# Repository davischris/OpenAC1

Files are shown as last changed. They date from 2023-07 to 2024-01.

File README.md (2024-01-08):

# OpenAC1

This work is largely based on the work of Tor-Eirik Bakke Lunde (https://github.com/tebl/RC6502-Apple-1-Replica).  I really liked his project and I had just read "Apple 1 Replica Creation: Back to the Garage" by Tom Owad, so I was very interested in making a "workalike" Apple 1.

I wanted to extend this project to include USB keyboard and VGA monitor support, as well as the ability to read programs from an SD card.

This project also includes code from other open source projects including Geoff Graham's VT100 Teminal Emulator (https://geoffg.net/terminal.html) including David Hansel's modification to use a USB keyboard.

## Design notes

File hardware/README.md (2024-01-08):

Schematic and circuit board were designed in KiCAD 6.0

ROM image should be burned to an AT28C64 EEPROM

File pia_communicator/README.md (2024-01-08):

Open .ino file in Arduino IDE for Arduino Nano

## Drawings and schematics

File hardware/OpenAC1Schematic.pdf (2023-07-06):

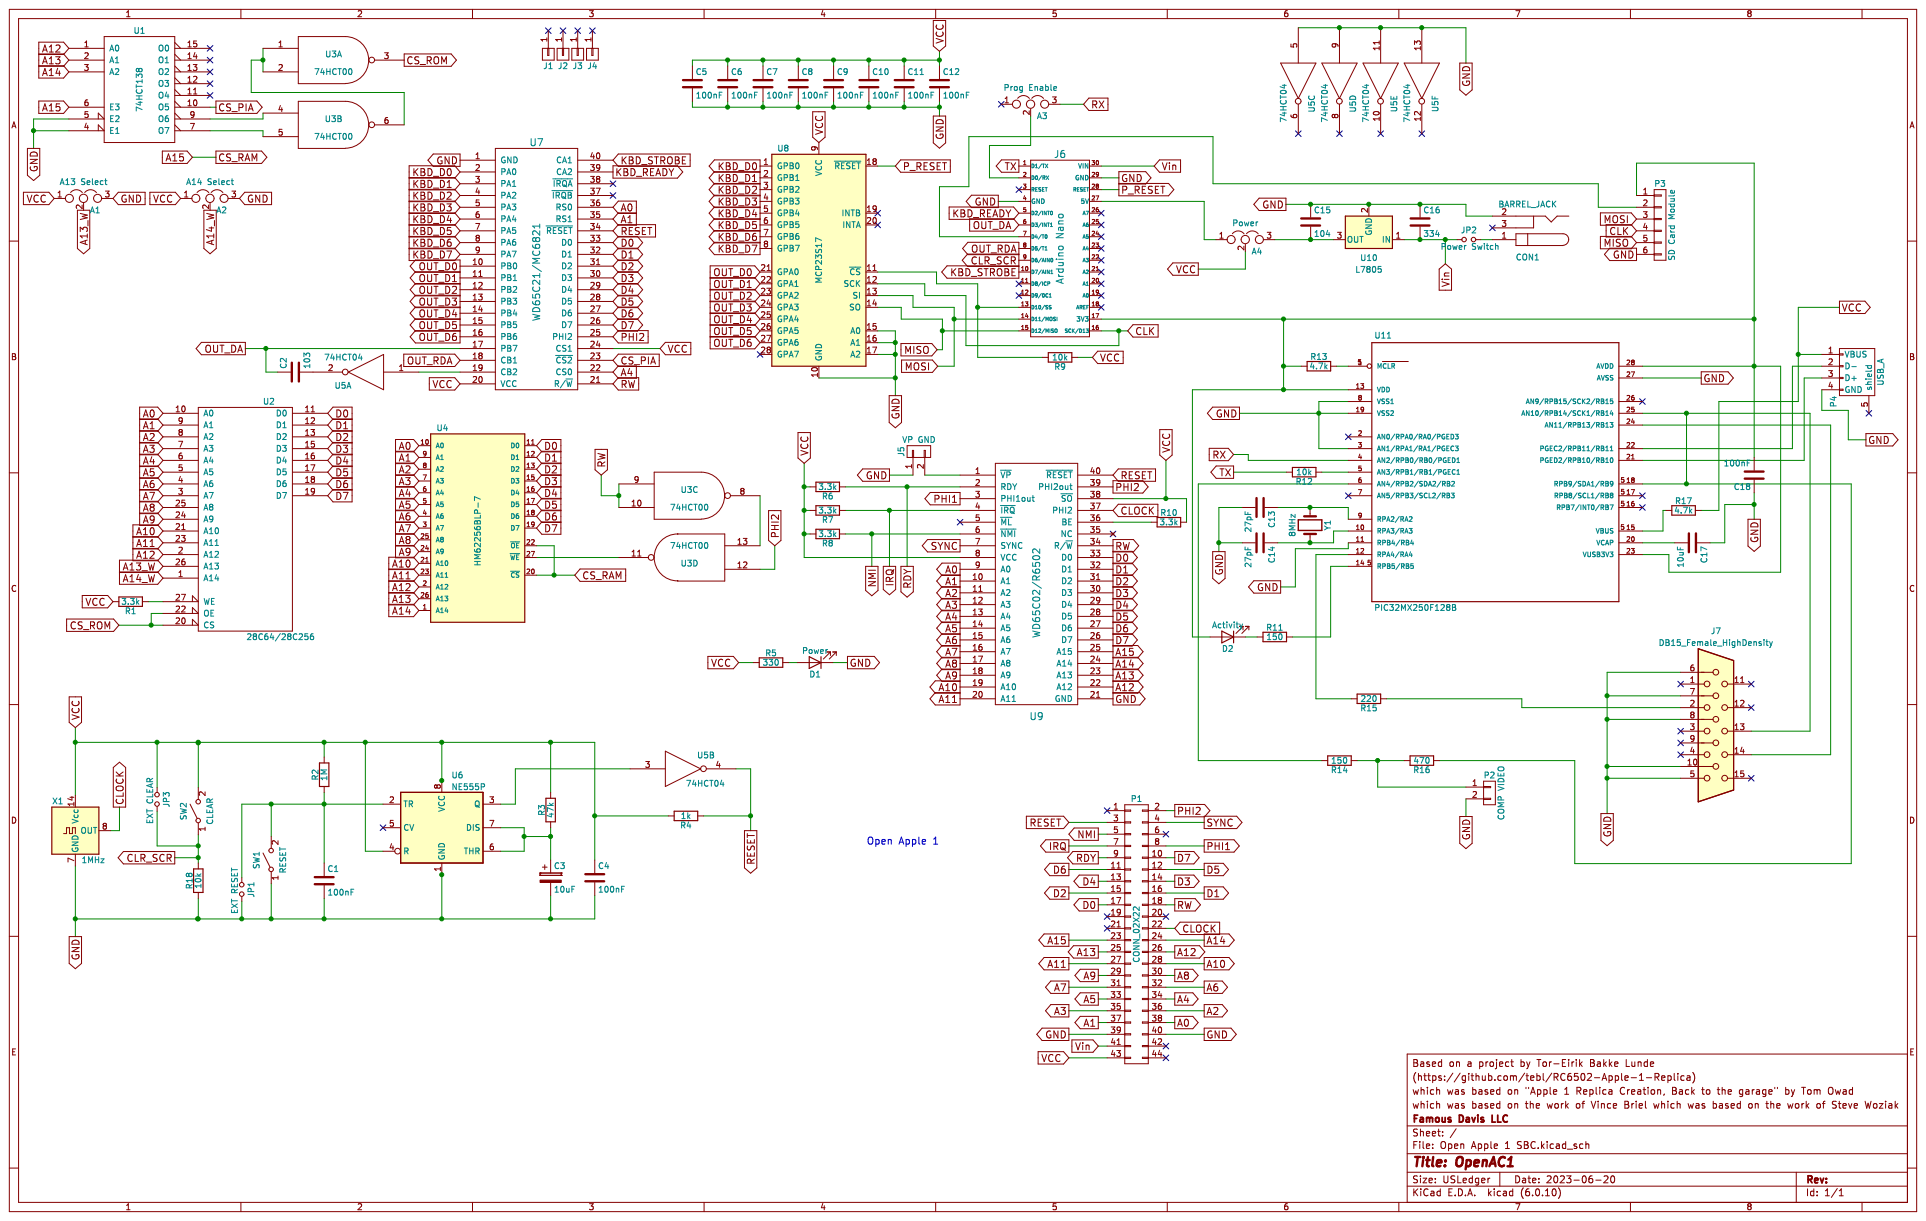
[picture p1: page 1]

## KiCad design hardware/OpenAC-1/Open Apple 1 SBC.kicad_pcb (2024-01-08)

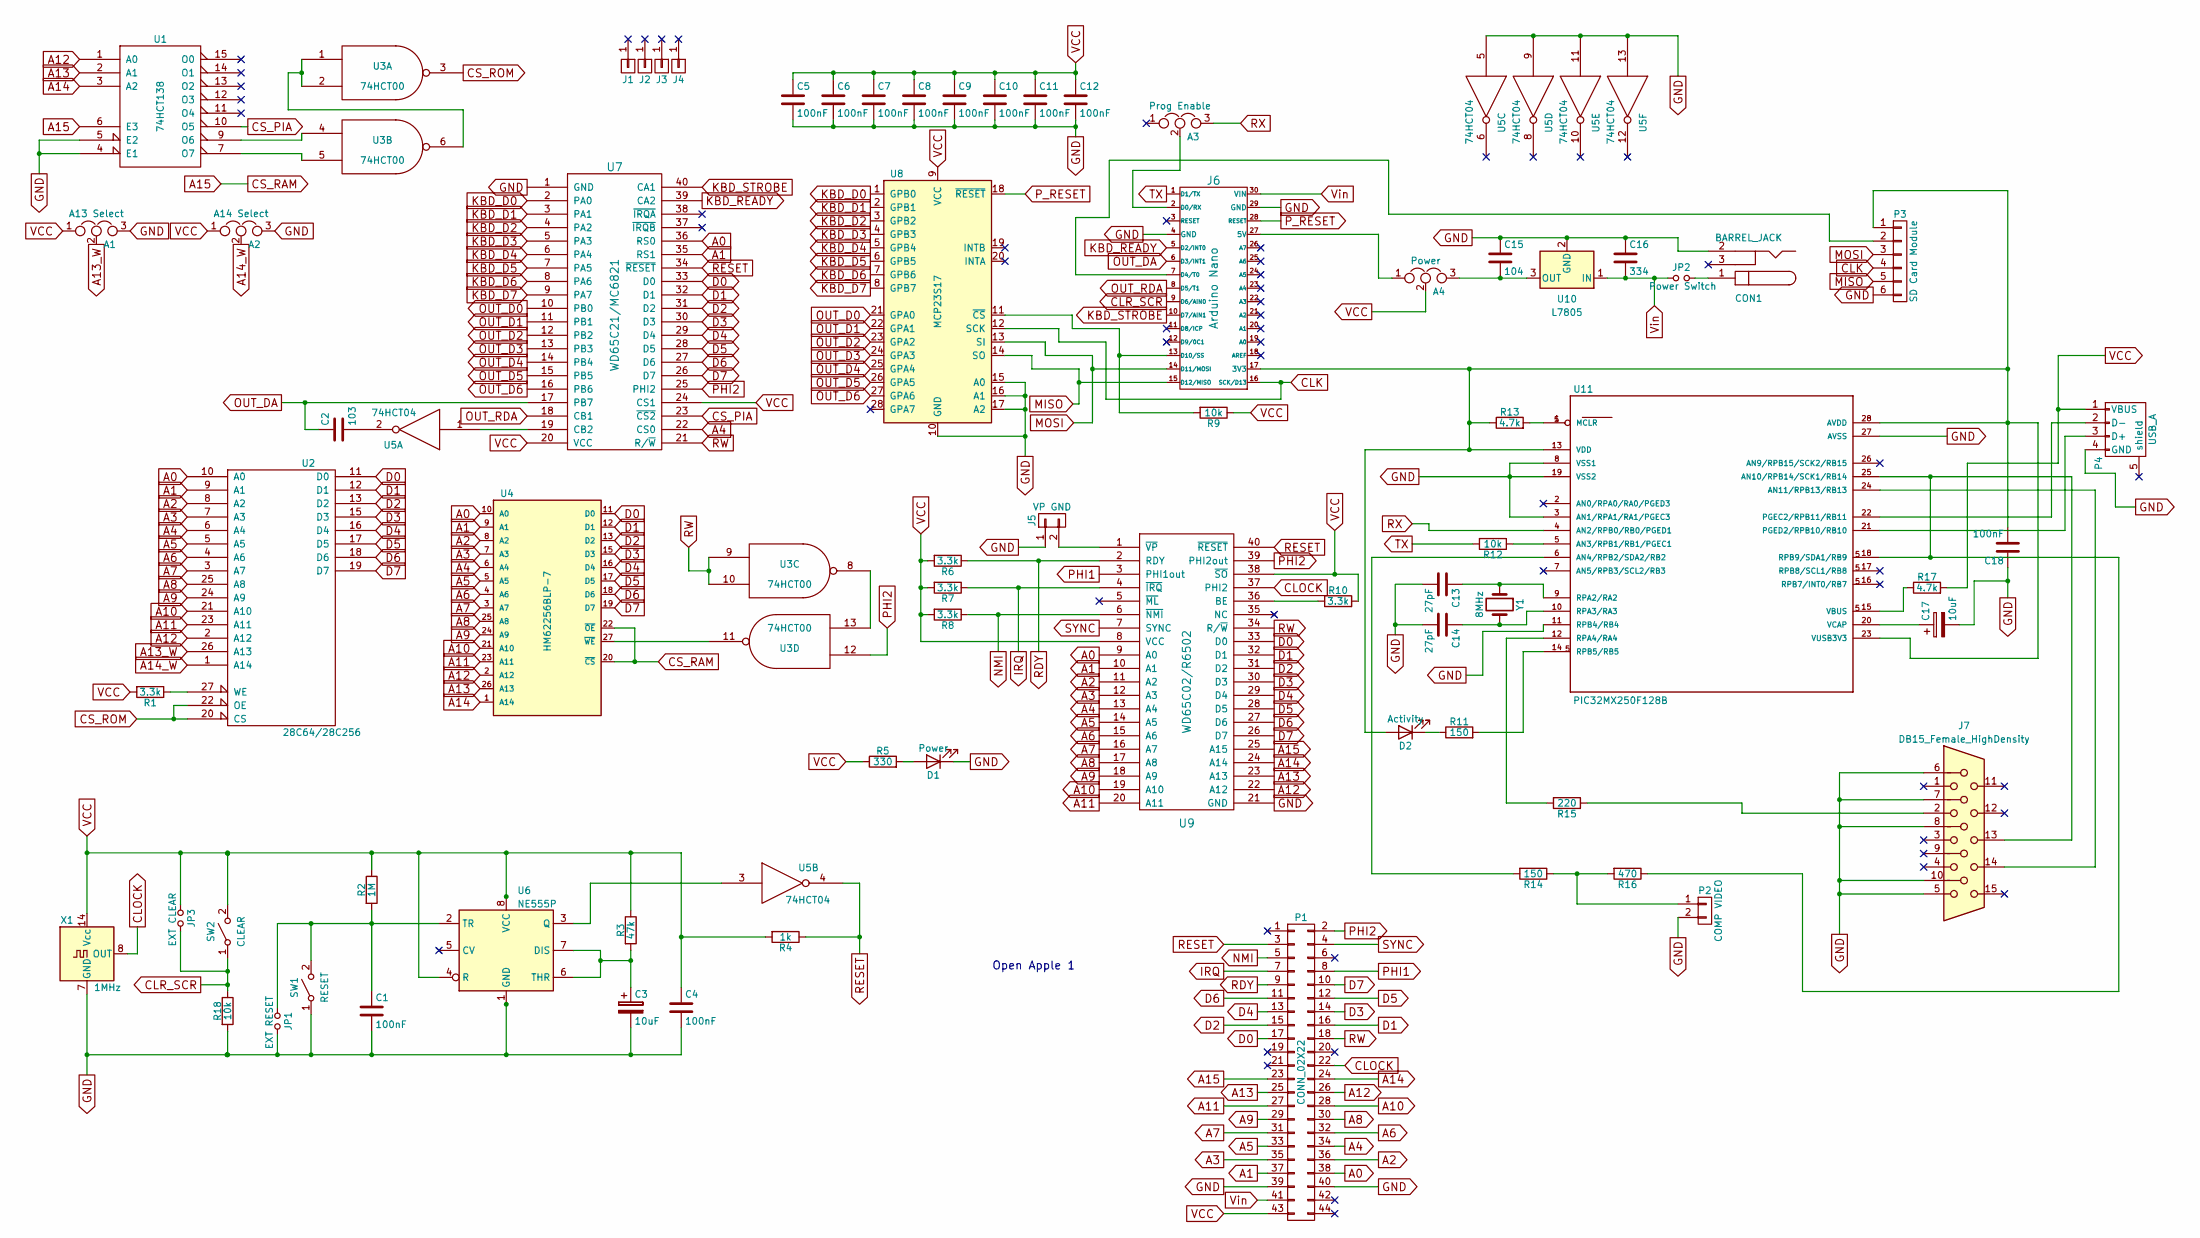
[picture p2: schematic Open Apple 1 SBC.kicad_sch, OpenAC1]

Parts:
A1: A13 Select; PinHeader_1x03_P2.54mm_Vertical
A2: A14 Select; PinHeader_1x03_P2.54mm_Vertical
A3: Prog Enable; PinHeader_1x03_P2.54mm_Vertical
A4: Power; PinHeader_1x03_P2.54mm_Vertical
C1, C4, C5, C6, C7, C8, C9, C10, C11, C12, C18: 100nF; C_Disc_D3.8mm_W2.6mm_P2.50mm
C2: 103; C_Disc_D4.3mm_W1.9mm_P5.00mm
C3, C17: 10uF; CP_Radial_D4.0mm_P2.00mm
C13, C14: 27pF; C_Disc_D3.8mm_W2.6mm_P2.50mm
C15: 104; C_Disc_D4.3mm_W1.9mm_P5.00mm
C16: 334; C_Disc_D4.3mm_W1.9mm_P5.00mm
CON1: BARREL_JACK; BarrelJack_Horizontal
D1: Power; LED_D5.0mm
D2: Activity; LED_D5.0mm
J1, J2, J3, J4: Hole; Mounting
J5: VP GND; PinHeader_1x02_P2.54mm_Vertical
J6: Arduino Nano; Arduino_Nano
J7: DB15_Female_HighDensity; DSUB-15-HD_Female_Horizontal_P2.29x1.98mm_EdgePinOffset3.03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
JP1: EXT RESET; PinHeader_1x02_P2.54mm_Vertical
JP2: Power Switch; PinHeader_1x02_P2.54mm_Vertical
JP3: EXT CLEAR; PinHeader_1x02_P2.54mm_Vertical
P1: CONN_02X22; PinHeader_2x22_P2.54mm_Vertical
P2: COMP VIDEO; PinHeader_1x02_P2.54mm_Vertical
P3: SD Card Module; PinHeader_1x06_P2.54mm_Vertical
P4: USB_A
R1, R6, R7, R8, R10: 3.3k; R_Axial_DIN0207_L6.3mm_D2.5mm_P10.16mm_Horizontal
R2: 1M; R_Axial_DIN0207_L6.3mm_D2.5mm_P10.16mm_Horizontal
R3: 47k; R_Axial_DIN0207_L6.3mm_D2.5mm_P10.16mm_Horizontal
R4: 1k; R_Axial_DIN0207_L6.3mm_D2.5mm_P10.16mm_Horizontal
R5: 330; R_Axial_DIN0207_L6.3mm_D2.5mm_P10.16mm_Horizontal
R9, R12, R18: 10k; R_Axial_DIN0207_L6.3mm_D2.5mm_P10.16mm_Horizontal
R11, R14: 150; R_Axial_DIN0207_L6.3mm_D2.5mm_P10.16mm_Horizontal
R13, R17: 4.7k; R_Axial_DIN0207_L6.3mm_D2.5mm_P10.16mm_Horizontal
R15: 220; R_Axial_DIN0207_L6.3mm_D2.5mm_P10.16mm_Horizontal
R16: 470; R_Axial_DIN0207_L6.3mm_D2.5mm_P10.16mm_Horizontal
SW1: RESET; SW_PUSH_6mm
SW2: CLEAR; SW_PUSH_6mm
U1: 74HCT138; DIP-16_W7.62mm
U2: 28C64/28C256; DIP-28_W15.24mm
U3: 74HCT00; DIP-14_W7.62mm
U4: HM62256BLP-7; DIP-28_W15.24mm
U5: 74HCT04; DIP-14_W7.62mm
U6: NE555P; DIP-8_W7.62mm
U7: WD65C21/MC6821; DIP-40_W15.24mm
U8: MCP23S17; DIP-28_W7.62mm
U9: WD65C02/R6502; DIP-40_W15.24mm
U10: L7805; TO-220-3_Vertical
U11: PIC32MX250F128B; DIP-28_W7.62mm
X1: 1MHz; Oscillator_DIP-14
Y1: 8MHz; Crystal_HC49-U_Vertical

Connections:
A0: P1.38, U2.10 (A0), U4.10 (A0), U7.36 (RS0), U9.9 (A0)
A1: P1.37, U2.9 (A1), U4.9 (A1), U7.35 (RS1), U9.10 (A1)
A2: P1.36, U2.8 (A2), U4.8 (A2), U9.11 (A2)
A3: P1.35, U2.7 (A3), U4.7 (A3), U9.12 (A3)
A4: P1.34, U2.6 (A4), U4.6 (A4), U7.22 (CS0), U9.13 (A4)
A5: P1.33, U2.5 (A5), U4.5 (A5), U9.14 (A5)
A6: P1.32, U2.4 (A6), U4.4 (A6), U9.15 (A6)
A7: P1.31, U2.3 (A7), U4.3 (A7), U9.16 (A7)
A8: P1.30, U2.25 (A8), U4.25 (A8), U9.17 (A8)
A9: P1.29, U2.24 (A9), U4.24 (A9), U9.18 (A9)
A10: P1.28, U2.21 (A10), U4.21 (A10), U9.19 (A10)
A11: P1.27, U2.23 (A11), U4.23 (A11), U9.20 (A11)
A12: P1.26, U1.1 (A0), U2.2 (A12), U4.2 (A12), U9.22 (A12)
A13: P1.25, U1.2 (A1), U4.26 (A13), U9.23 (A13)
A13_W: A1.2, U2.26 (A13)
A14: P1.24, U1.3 (A2), U4.1 (A14), U9.24 (A14)
A14_W: A2.2, U2.1 (A14)
A15: P1.23, U1.6 (E3), U4.20 (~CS), U4.22 (~OE), U9.25 (A15)
CLK: J6.16 (SCK/D13), P3.4, U8.12 (SCK)
CLOCK: P1.22, U9.37 (PHI2), X1.8 (OUT)
CLR_SCR: J6.9 (D6/AIN0), JP3.2, R18.1, SW2.1 (A)
CS_PIA: U1.10 (O5), U7.23 (~CS2)
CS_ROM: U2.20 (CS), U2.22 (OE), U3.3
D0: P1.17, U2.11 (D0), U4.11 (D0), U7.33 (D0), U9.33 (D0)
D1: P1.16, U2.12 (D1), U4.12 (D1), U7.32 (D1), U9.32 (D1)
D2: P1.15, U2.13 (D2), U4.13 (D2), U7.31 (D2), U9.31 (D2)
D3: P1.14, U2.15 (D3), U4.15 (D3), U7.30 (D3), U9.30 (D3)
D4: P1.13, U2.16 (D4), U4.16 (D4), U7.29 (D4), U9.29 (D4)
D5: P1.12, U2.17 (D5), U4.17 (D5), U7.28 (D5), U9.28 (D5)
D6: P1.11, U2.18 (D6), U4.18 (D6), U7.27 (D6), U9.27 (D6)
D7: P1.10, U2.19 (D7), U4.19 (D7), U7.26 (D7), U9.26 (D7)
GND: A1.3, A2.3, C1.2, C3.2, C4.2, C5.2, C6.2, C7.2, C8.2, C9.2, C10.2, C11.2, C12.2, C13.2, C14.2, C15.1, C16.1, C17.2, C18.1, CON1.2, D1.1 (K), J5.1, J6.4 (GND), J6.29 (GND), J7.5, J7.6, J7.7, J7.8, J7.10, JP1.2, P1.39, P1.40, P2.2, P3.6, P4.4 (GND), R18.2, SW1.1 (A), U1.4 (E1), U1.5 (E2), U1.8 (GND), U2.14 (GND), U3.7 (GND), U4.14 (GND), U5.5, U5.7 (GND), U5.9, U5.11, U5.13, U6.1 (GND), U7.1 (GND), U8.10 (GND), U8.15 (A0), U8.16 (A1), U8.17 (A2), U9.21 (GND), U10.2 (GND), U11.3 (AN1/RPA1/RA1/PGEC3), U11.8 (VSS1), U11.11 (RPB4/RB4), U11.19 (VSS2), U11.27 (AVSS), X1.7 (GND)
IRQ: P1.7, R7.1, U9.4 (~IRQ)
KBD_D0: U7.2 (PA0), U8.1 (GPB0)
KBD_D1: U7.3 (PA1), U8.2 (GPB1)
KBD_D2: U7.4 (PA2), U8.3 (GPB2)
KBD_D3: U7.5 (PA3), U8.4 (GPB3)
KBD_D4: U7.6 (PA4), U8.5 (GPB4)
KBD_D5: U7.7 (PA5), U8.6 (GPB5)
KBD_D6: U7.8 (PA6), U8.7 (GPB6)
KBD_D7: U7.9 (PA7), U8.8 (GPB7)
KBD_READY: J6.5 (D2/INT0), U7.39 (CA2)
KBD_STROBE: J6.10 (D7/AIN1), U7.40 (CA1)
MISO: J6.15 (D12/MISO), P3.5, U8.14 (SO)
MOSI: J6.14 (D11/MOSI), P3.3, U8.13 (SI)
NMI: P1.5, R8.1, U9.6 (~NMI)
unnamed: A3.2, J6.2 (D0/RX)
unnamed: A4.1, J6.27 (5V)
unnamed: A4.3, C15.2, U10.3 (OUT)
unnamed: C1.1, JP1.1, R2.2, SW1.2 (B), U6.2 (TR)
unnamed: C2.2, U5.2
unnamed: C3.1, R3.2, U6.6 (THR), U6.7 (DIS)
unnamed: C13.1, U11.9 (RPA2/RA2), Y1.1
unnamed: C14.1, U11.10 (RPA3/RA3), Y1.2
unnamed: C17.1, U11.20 (VCAP)
unnamed: C18.2, D2.2 (A), J6.17 (3V3), P3.1, R13.1, U11.13 (VDD), U11.23 (VUSB3V3), U11.28 (AVDD)
unnamed: CON1.1, JP2.2
unnamed: D1.2 (A), R5.2
unnamed: D2.1 (K), R11.1
unnamed: J5.2, U9.1 (~VP)
unnamed: J6.7 (D4/T0), P3.2
unnamed: J6.13 (D10/SS), R9.2, U8.11 (~CS)
unnamed: J7.2, R15.1
unnamed: J7.13, R16.1, U11.18 (RPB9/SDA1/RB9), U11.25 (AN10/RPB14/SCK1/RB14)
unnamed: J7.14, U11.24 (AN11/RPB13/RB13)
unnamed: P2.1, R14.1, R16.2
unnamed: P4.2 (D-), U11.22 (PGEC2/RPB11/RB11)
unnamed: P4.3 (D+), U11.21 (PGED2/RPB10/RB10)
unnamed: R1.1, U2.27 (WE)
unnamed: R10.1, U9.36 (BE)
unnamed: R11.2, U11.14 (RPB5/RB5)
unnamed: R12.1, U11.5 (AN3/RPB1/RB1/PGEC1)
unnamed: R13.2, U11.1 (MCLR)
unnamed: R14.2, U11.6 (AN4/RPB2/SDA2/RB2)
unnamed: R15.2, U11.12 (RPA4/RA4)
unnamed: R17.1, U11.15 (VBUS)
unnamed: U1.7 (O7), U3.5
unnamed: U1.9 (O6), U3.4
unnamed: U3.1, U3.2, U3.6
unnamed: U3.11, U4.27 (~WE)
unnamed: U3.8, U3.13
unnamed: U5.1, U7.19 (CB2)
unnamed: U5.3, U6.3 (Q)
OUT_D0: U7.10 (PB0), U8.21 (GPA0)
OUT_D1: U7.11 (PB1), U8.22 (GPA1)
OUT_D2: U7.12 (PB2), U8.23 (GPA2)
OUT_D3: U7.13 (PB3), U8.24 (GPA3)
OUT_D4: U7.14 (PB4), U8.25 (GPA4)
OUT_D5: U7.15 (PB5), U8.26 (GPA5)
OUT_D6: U7.16 (PB6), U8.27 (GPA6)
OUT_DA: C2.1, J6.6 (D3/INT1), U7.17 (PB7)
OUT_RDA: J6.8 (D5/T1), U7.18 (CB1)
PHI1: P1.8, U9.3 (PHI1out)
PHI2: P1.2, U3.12, U7.25 (PHI2), U9.39 (PHI2out)
P_RESET: J6.28 (RESET), U8.18 (~RESET)
RDY: P1.9, R6.1, U9.2 (RDY)
RESET: P1.3, R4.1, U5.4, U7.34 (~RESET), U9.40 (~RESET)
RW: P1.18, U3.9, U3.10, U7.21 (R/~W), U9.34 (R/~W)
RX: A3.3, U11.4 (AN2/RPB0/RB0/PGED1)
SYNC: P1.4, U9.7 (SYNC)
TX: J6.1 (D1/TX), R12.2
VCC: A1.1, A2.1, A4.2, C4.1, C5.1, C6.1, C7.1, C8.1, C9.1, C10.1, C11.1, C12.1, JP3.1, P1.43, P4.1 (VBUS), R1.2, R2.1, R3.1, R4.2, R5.1, R6.2, R7.2, R8.2, R9.1, R10.2, R17.2, SW2.2 (B), U1.16 (VCC), U2.28 (VCC), U3.14 (VCC), U4.28 (VCC), U5.14 (VCC), U6.4 (R), U6.8 (VCC), U7.20 (VCC), U7.24 (CS1), U8.9 (VCC), U9.8 (VCC), U9.38 (~SO), X1.14 (Vcc)
Vin: C16.2, J6.30 (VIN), JP2.1, P1.41, U10.1 (IN)

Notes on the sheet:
Open Apple 1

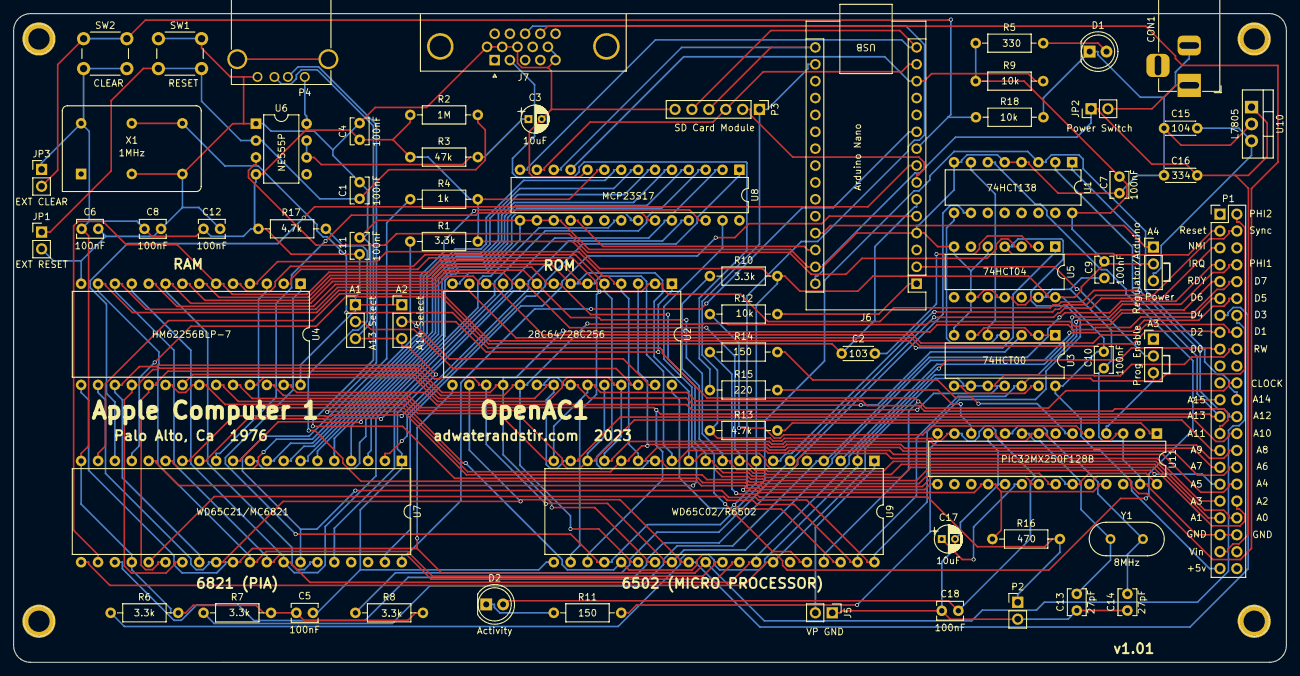
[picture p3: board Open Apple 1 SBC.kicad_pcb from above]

Board: 2 copper layers, 191.5 x 97.6 mm, 72 parts (0 on the bottom side), 103 nets.

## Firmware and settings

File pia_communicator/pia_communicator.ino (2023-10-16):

#include <SPI.h>
#include <MCP23S17.h>
#include <SD.h>

#define KBD_INTERRUPT_ENABLE true
#define KBD_SEND_TIMEOUT_MS 2000

#define IO_SS 10

#define IO_VIDEO 0
#define IO_VIDEO_D0 0
#define IO_VIDEO_D6 6
#define VIDEO_RDA 5
#define VIDEO_DA 3

#define IO_KBD 1
#define IO_KBD_D0 8
#define IO_KBD_D6 14
#define IO_KBD_DA 15
#define KBD_READY 2
#define KBD_STROBE 7    //was 4, needed to free up for sd module
#define LED 13
#define CLRSCR 6

// How long to delay after sending a character to video terminal (ms)
#define VIDEO_CHARACTER_DELAY 5
// How long to delay after sending a character to the PIA/6802
#define PIA_CHARACTER_DELAY 5
// How long to delay after writing a full line to the PIA/6802
#define PIA_LINE_DELAY 150

static int delay_after_line_ms = PIA_LINE_DELAY;
static volatile char video_byte;
static bool loading_file;

MCP23S17 bridge(&SPI, IO_SS, 0);
File root;
const int chipSelect = 4;
String command;
File firstFile;
File myRecFile;
int captureType;
bool firstByte;
int countUp = -32767;
int buttonState = 0;        // current state of the button

static volatile bool video_data_ready;
static volatile bool keyboard_data_sent_ok;

static void on_video_data_ready(void) {
  digitalWrite(VIDEO_RDA, LOW);
  video_byte = bridge.readPort(IO_VIDEO) & 127;
  video_data_ready = true;
}

static void on_keyboard_data_ack(void) {
  keyboard_data_sent_ok = true;
}

/**
 * We signal to the 6802/PIA that we are ready to accept
 * video data by a low-to-high transition on the VIDEO_RDA pin.
 */
static void signal_ready_for_video(void) {
  digitalWrite(VIDEO_RDA, LOW);
  delay(100);
  digitalWrite(VIDEO_RDA, HIGH);
}

void setup() {
  pinMode(LED, OUTPUT);
  Serial.begin(38400);
  configure_pins();
  configure_bridge();
  //output_status();
  Serial.println("\033[f");
  Serial.print(".");

  Serial.print(".");
  digitalWrite(VIDEO_RDA, LOW);
  delay(2000);
  digitalWrite(VIDEO_RDA, HIGH);
  Serial.println("\033[2J");
  delay(100);
  Serial.println("\033[f");
  loading_file = false;
}

void configure_pins() {
  pinMode(KBD_READY, INPUT);
  pinMode(VIDEO_DA, INPUT);
  pinMode(KBD_STROBE, OUTPUT);
  pinMode(VIDEO_RDA, OUTPUT);

  // initialize the button pin as a input:
  pinMode(CLRSCR, INPUT);

  /* Test the use of interrupts for communication with the PIA */
  attachInterrupt(digitalPinToInterrupt(KBD_READY), on_keyboard_data_ack, FALLING);
  attachInterrupt(digitalPinToInterrupt(VIDEO_DA), on_video_data_ready, RISING);
}

void configure_bridge() {
  bridge.begin();

  /* Configure video section 
  for (int i = IO_VIDEO_D0; i <= IO_VIDEO_D6; i++) {
    bridge.pinMode(i, INPUT);
  }*/
  bridge.pinMode(7, INPUT_PULLUP);

  /* Configure keyboard section */
  for (int i = 8; i <= 15; i++) {
    bridge.pinMode(i, OUTPUT);
  }
}

void show_directory() {
  int numTabs = 0;
  Serial.println(" ");
  root = SD.open("/");
  printDirectory(root, 0);
  root.close();
}

String formatFilename(File entry) {
  char s[80];
  char n[70];
  String tmp;
  int fileLen;
  
  tmp = entry.name();
  tmp.toUpperCase();
  tmp.toCharArray(n, tmp.length()+1);
  fileLen = entry.size()/1000;
  if (fileLen == 0)
    fileLen = 1;
  if (tmp.endsWith("BIN")) {
    sprintf(s, "B  %03d  %s", fileLen, n);
  } else if (tmp.endsWith("BAS")) {
    sprintf(s, "I  %03d  %s", fileLen, n);
  }

  //remove files that begin with "." (in case this card was inserted into a Mac)
  if (n[0] == '.' || n[0] == '_')
    s[0] = '\0';
  return String(s);
}

void printDirectory(File dir, int numTabs) {
  int numFiles = 0;
  String fName;
  
  while (true) {

    File entry =  dir.openNextFile();
    if (! entry) {
      // no more files
      dir.rewindDirectory();
      break;
    }
    for (uint8_t i = 0; i < numTabs; i++) {
      Serial.print('\t');
    }
    if (!entry.isDirectory()) {
      if (numFiles == 0) {  //we have to do this goofy thing because the catalog will skip the first file after loading a program
        if (firstFile.name() == "")
          firstFile = entry;
        else
          if (firstFile.name() != entry.name()) {
            fName = formatFilename(firstFile);
            if (fName.charAt(0) == 'B' || fName.charAt(0) == 'I')
            {
              Serial.println(fName);
              numFiles++;
            }
          }
      }
      fName = formatFilename(entry);
      if (fName.charAt(0) == 'B' || fName.charAt(0) == 'I')
      {
        Serial.println(fName);
        numFiles++;
      }
    }
    entry.close();

    //pause for long listings
    if (numFiles > 0 && numFiles % 18 == 0) {
      Serial.println("Press any key...");
      Serial.flush();
      while(!Serial.available()) {
      }
      int c = Serial.read();
      Serial.flush();
    }
  }
}

void print_hex(byte value) {
  print_hex(value, true);
}

void print_hex(byte value, bool newline) {
  if (value <= 0xF) {
    Serial.print("0x0");
  } else {
    Serial.print("0x");
  }

  if (newline) Serial.println(value, HEX);
  else Serial.print(value, HEX);
}

void serial_receive() {
  if (Serial.available() > 0) {
    int c = Serial.read();
    pia_send(c);
  }
}

void load_file(String filename, int start_line = -1, int end_line = -1) {
  if (!SD.exists(filename)) {
    Serial.println("File does not exist.");
    return;
  }
  loading_file = true;
  
  File myFile = SD.open(filename);

  //switch to BASIC or Wozmon based on the file extension
  int len = strlen(myFile.name());
  if (strstr(strlwr(myFile.name() + (len - 4)), ".bas"))
  {
    for(auto x : "E000R")
    {
      send_key(x);
      process_video();
    }
    send_key(13);
    process_video();
    delay(500);    
  } else if (strstr(strlwr(myFile.name() + (len - 4)), ".bin"))
  {
    for(auto x : "CALL -151")
    {
      send_key(x);
      process_video();
    }
    send_key(13);
    process_video();
    delay(500);    
  }

  if (start_line != -1) {
    if (end_line == -1) {
      // Assume user only wants to load a single line
      end_line = start_line;
    }
    else if (end_line <= start_line) {
      end_line = start_line + 10;
    }
    Serial.print("Loading lines ");
    Serial.print(String(start_line));
    Serial.print(" to ");
    Serial.println(String(end_line));
  }

  if (!myFile) {
    Serial.println("Could not open file ...");
    loading_file = false;
    return;
  }

  int line_number = 1;
  char last;
  while (myFile.available()) {
    char ch = myFile.read();
    if (last == 10 || last == 13 && (ch != 10 && ch != 13)) {
      line_number++;
    }
    if (ch == 10) ch = 13;

    if (start_line == -1) {
      // We are transmitting all lines ...
      send_key(ch);
      process_video();
    }
    else if (line_number >= start_line && line_number <= end_line) {
      // We are transmitting only selected lines ...
      send_key(ch);
      process_video();
    }
    last = ch;
  }
  myFile.rewindDirectory();
  myFile.close();
  loading_file = false;
  if (firstFile.name() != "")              //we have to do this because some goofy thing makes the catalog listing stuck on whatever file was loaded
    bool b = SD.exists(firstFile.name());
}

String getValue(String data, char separator, int index)
{
  int found = 0;
  int strIndex[] = {0, -1};
  int maxIndex = data.length()-1;

  for(int i=0; i<=maxIndex && found<=index; i++){
    if(data.charAt(i)==separator || i==maxIndex){
        found++;
        strIndex[0] = strIndex[1]+1;
        strIndex[1] = (i == maxIndex) ? i+1 : i;
    }
  }

  return found>index ? data.substring(strIndex[0], strIndex[1]) : "";
}

void pia_send(int c) {
  char ch;

  c = map_to_ascii(c);

  /* Output the actual keys as long as it's supported */
  if (c < 96) {
    if (c == 13) { 
      int cmdLen = command.length();
      //Serial.println("\rCommand: " + command);
      if (cmdLen > 6) {   //if it's short, we don't need to parse it.
        command.trim();
        if (command == "CATALOG") {
          if (!SD.begin(chipSelect))
            Serial.println("initialize SD card failed");
          else
            show_directory();
          //send_key(27);
          for (int i = 0; i < cmdLen; i++) {
            send_key(95);
          }
          c = 13;
        } else if (command.startsWith("LOAD ", 0)) {
          Serial.println("");
          for (int i = 0; i < cmdLen; i++) {
            send_key(95);
          }
          send_key(13);
          if (!SD.begin(chipSelect))
            Serial.println("initialize SD card failed");
          else
          {
            String filename = command.substring(5);
            int start_line = -1, end_line = -1;
            if (filename) {
              int pos = filename.indexOf(' ');
              if (pos != -1) {
                String s = filename.substring(pos + 1); // start
                filename = filename.substring(0, pos);
                int pos2 = s.indexOf(',');
                if (pos2 != -1) {
                  String e = s.substring(pos2 + 1); // end
                  s = s.substring(0, pos2);
                  end_line = e.toInt();
                }
                start_line = s.toInt();
              }
              if (start_line == 0) {
                start_line = -1;
              }
              load_file(filename, start_line, end_line);
            }
            else {
              Serial.println("You must specify a filename.");
            }
          }
        } else if (command.startsWith("TIMEOUT", 0)) {
          if (command.length() == 7) {
            Serial.println("\n\rLINE TIMEOUT VALUE IS " + String(delay_after_line_ms));
          }
          else {
            String timeout = command.substring(8);
            delay_after_line_ms = timeout.toInt();
            Serial.println("\n\rLINE TIMEOUT VALUE CHANGED TO " + String(delay_after_line_ms));
          }
          for (int i = 0; i < cmdLen; i++) {
            send_key(95);
          }
          c = 13;
        }
      }
      command = "";
    } else {
      char ch = c;
      //if this is a rubout character, then delete the last character from our command string
      if (ch == '_') {
        int lastIndex = command.length() - 1;
        if (lastIndex >= 0)
          command.remove(lastIndex);
      } else
        command.concat(ch);
    }

    send_key(c);
  }
}

/*
   Transmit character

   @note    This function will return 1 if an acknowledgement is not received
            within the specified time.

   @return  0 on success
            1 on failure
*/
int resend_key(int c) {
  /* Make sure STROBE signal is off */
  digitalWrite(KBD_STROBE, LOW);

  delayMicroseconds(750);
  /* Notify PIA that we have sent a new keyboard character */
  digitalWrite(KBD_STROBE, HIGH);
  
  //we're skipping the rest of this process for now.  It seems to cause more troubles than it solves.
  if (!loading_file) {
    signal_ready_for_video();
    return 0;
  }

  /* Wait for PIA to acknowledge this.
    -> We are waiting for a falling edge on the KBD_READY pin.
    -> Once this occurs the keyboard_data_sent_ok flag will be set in the interrupt
  */
  uint32_t t_send = millis();
  while (!keyboard_data_sent_ok) {
    // Ensure we process any new video data while waiting ...
    //process_video();  // Remove this line because it was causing repeating characters on the video display
    uint32_t t_now = millis();
    if (t_now - t_send >= KBD_SEND_TIMEOUT_MS) {
      Serial.println("KBD TIMEOUT");
      return 1;
    }
  }

  return 0;
}

void delay_while_processing_video(int ms) {
  uint32_t t_start = millis();
  while (1) {
    process_video();
    uint32_t t_now = millis();
    if (t_now >= t_start + ms) {
      break;
    }
  }
}

void send_key(int c) {
  const int max_tries = 3;

  /* Write new character on I/O expander */
  bridge.writePort(IO_KBD, c | 128);

  /*
    Notify 6802 and/or PIA that a new character is waiting to be read, and
    then wait for an acknowledgement.
  */
  int attempt = 1;
  int rc = 1;
  while (rc != 0) {
    rc = resend_key(c);
    if (rc == 0) {
      break; // succeeded
    }
    // If we did not receive an acknowledgement that the character
    // was read, try again. Maybe the PIA or 6802 just missed the
    // relevant transition.
    if (attempt++ >= max_tries) {
      Serial.println("TOO MANY ATTEMPTS. SKIPPING CHARACTER.");
      break;
    }
    /** 
     * The 6802 might be stuck in a loop waiting to send us video 
     * data - as it might have missed our last 'ready for video'
     * signal.
     * Just re-signal that we are ready.
     */
    signal_ready_for_video();
  }

  keyboard_data_sent_ok = false;
  digitalWrite(KBD_STROBE, LOW);
  if (c == 13) {
    // Use a longer delay after sending a full line - in case
    // the 6802 needs more time to process
    delay_while_processing_video(delay_after_line_ms);
  }
  else {
    delay(PIA_CHARACTER_DELAY);
  }
}

char map_to_ascii(int c) {
  if (c >= 128) {
    Serial.print("Non-printable character: 0x");
    Serial.println(c, HEX);
  }
  /* Convert ESC key */
  if (c == 203) {
    c = 27;
  }

  /* Ctrl A-Z */
  if (c > 576 && c < 603) {
    c -= 576;
  }

  /* Convert lowercase keys to UPPERCASE */
  if (c > 96 && c < 123) {
    c -= 32;
  }

  /* Convert backspace to underscore */
  if (c == 8) {
    c = 95;
  }

  return c;
}

char send_ascii(char c) {
  switch (c) {
    case 0x0d: Serial.println(); /* Replace CR with LF */
    default:
      Serial.print(c);
  }
}

void process_video(void) {
  if (video_data_ready) {
    video_data_ready = false;
    send_ascii(video_byte);
    
    delay(VIDEO_CHARACTER_DELAY);
    digitalWrite(VIDEO_RDA, HIGH);
  } 
  else if (!loading_file) {
    countUp++;
    if (countUp == 32767) {
      signal_ready_for_video();
      countUp = -32767;
    }
  }
}

void loop() {
  // read the pushbutton input pin:
  buttonState = digitalRead(CLRSCR);
  if (buttonState == HIGH) {
    Serial.println("\033[2J");
    delay(100);
    Serial.println("\033[f");
  }
  serial_receive();
  // serial_transmit();
  process_video();
}

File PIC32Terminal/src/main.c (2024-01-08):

/*****************************************************************************************************************************

Main.c

	Copyright (C) 2014 Geoff Graham (projects@geoffg.net)
	All rights reserved.

	This file and the program created from it are FREE FOR COMMERCIAL AND
	NON-COMMERCIAL USE as long as the following conditions are aheared to.

	Copyright remains Geoff Graham's, and as such any Copyright notices in the
	code are not to be removed.  If this code is used in a product, Geoff Graham
	should be given attribution as the author of the parts used.  This can be in
	the form of a textual message at program startup or in documentation (online
	or textual) provided with the program or product.

	Redistribution and use in source and binary forms, with or without modification,
	are permitted provided that the following conditions  are met:
	1. Redistributions of source code must retain the copyright notice, this list
	   of conditions and the following disclaimer.
	2. Redistributions in binary form must reproduce the above copyright notice, this
	   list of conditions and the following disclaimer in the documentation and/or
	   other materials provided with the distribution.
	3. All advertising materials mentioning features or use of this software must
	   display the following acknowledgement:
	   This product includes software developed by Geoff Graham (projects@geoffg.net)

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
	The licence and distribution terms for any publically available version or
	derivative of this code cannot be changed.  i.e. this code cannot simply be copied
	and put under another distribution licence (including the GNU Public Licence).

********************************************************************************************************************************/

#define _SUPPRESS_PLIB_WARNING
#define _DISABLE_OPENADC10_CONFIGPORT_WARNING

#include <plib.h>									// peripheral libraries
#include <string.h>
#include <stdio.h>
#include <ctype.h>
#include "Terminal.h"
#include "video.h"
#include "vt100.h"

// declare the serial I/O functions
void initSerial(void);
int getSerial(void);
void putSerial(int c);

void initTimer(void);

void BlinkLED(void);
void SetUp(void);


char *SerialRxBuf;
int RxBufferSize;
volatile int SerialRxBufHead = 0;
volatile int SerialRxBufTail = 0;

#define SERIAL_TX_BUF_SIZE 256
char SerialTxBuf[SERIAL_TX_BUF_SIZE];
int SerialTxBufHead = 0;
int SerialTxBufTail = 0;

volatile int LEDTimer = 0;
int CursorOff = false;
volatile int CursorTimer = 0;
volatile int GeneralTimer;

//#define MES_SIGNON  "\rASCII Video Terminal Ver " VERSION "\r\n"\
//  "Copyright " YEAR " Geoff Graham\r\n" \
//  "USB Keyboard (c) 2018 David Hansel\r\n" \
//  "Apple 1 mods (c) " YEAR " Chris Davis\r\n\r\n" \
//  "Open Apple 1"

//CLD new signon
#define MES_SIGNON "_@_@_@_@_@_@_@_@_@_@_@_@_@_@_@_@_@_@_@_@\r\n" \
  "_@_@_@_@_@_@_@_@_@_@_@_@_@_@_@_@_@_@_@_@\r\n" \
  "_@_@_@_@_@_@_@_@_@_@_@_@_@_@_@_@_@_@_@_@\r\n" \
  "_@_@_@_@_@_@_@_@_@_@_@_@_@_@_@_@_@_@_@_@\r\n" \
  "_@_@_@_@_@_@_@_@_@_@_@_@_@_@_@_@_@_@_@_@\r\n" \
  "_@_@_@_@_@_@_@_@_@_@_@_@_@_@_@_@_@_@_@_@\r\n" \
  "_@_@_@_@_@_@_@_@_@_@_@_@_@_@_@_@_@_@_@_@\r\n" \
  "_@_@_@_@_@_@_@_@_@_@_@_@_@_@_@_@_@_@_@_@\r\n" \
  "_@_@_@_@_@_@_@_@_@_@_@_@_@_@_@_@_@_@_@_@\r\n" \
  "_@_@_@_@_@_@_@_@_@_@_@_@_@_@_@_@_@_@_@_@\r\n" \
  "_@_@_@_@_@_@_@_@_@_@_@_@_@_@_@_@_@_@_@_@\r\n" \
  "_@_@_@_@_@_@_@_@_@_@_@_@_@_@_@_@_@_@_@_@\r\n" \
  "_@_@_@_@_@_@_@_@_@_@_@_@_@_@_@_@_@_@_@_@\r\n" \
  "_@_@_@_@_@_@_@_@_@_@_@_@_@_@_@_@_@_@_@_@\r\n" \
  "_@_@_@_@_@_@_@_@_@_@_@_@_@_@_@_@_@_@_@_@\r\n" \
  "_@_@_@_@_@_@_@_@_@_@_@_@_@_@_@_@_@_@_@_@\r\n" \
  "_@_@_@_@_@_@_@_@_@_@_@_@_@_@_@_@_@_@_@_@\r\n" \
  "_@_@_@_@_@_@_@_@_@_@_@_@_@_@_@_@_@_@_@_@\r\n" \
  "_@_@_@_@_@_@_@_@_@_@_@_@_@_@_@_@_@_@_@_@\r\n" \
  "_@_@_@_@_@_@_@_@_@_@_@_@_@_@_@_@_@_@_@_@\r\n" \
  "_@_@_@_@_@_@_@_@_@_@_@_@_@_@_@_@_@_@_@_@\r\n" \
  "_@_@_@_@_@_@_@_@_@_@_@_@_@_@_@_@_@_@_@_@\r\n" \
  "_@_@_@_@_@_@_@_@_@_@_@_@_@_@_@_@_@_@_@_@\r\n" \
  "_@_@_@_@_@_@_@_@_@_@_@_@_@_@_@_@_@_@_@_@"

int main(int argc, char* argv[]) {
    int ch;

    SYS_Initialize(NULL);
    
	// initial setup of the I/O ports
    ANSELA = 0; ANSELB = 0;			                                // Default all pins to digital
    mJTAGPortEnable(0);                                             // turn off jtag

 	// setup the CPU
    SYSTEMConfigPerformance(CLOCKFREQ);    							// System config performance
	mOSCSetPBDIV(OSC_PB_DIV_1);									    // fix the peripheral bus to the main clock speed

    // clear all port I/O (they are not cleared by a software reset)
    LATA = LATB = 0;
    TRISA = TRISB = 0xffffffff;
    CNENA = CNENB = CNCONA = CNCONB = 0;
    CNPUA = CNPUB = CNPDA = CNPDB = 0;

    CNPUBSET = (1 << 4); CNPUBSET = (1 << 3); CNPUASET = (1 << 1);  // set pullups on the baudrate jumpers
    TRISBbits.TRISB5 = 0; LATBCLR = (1<<5);                         // turn on the power LED
    uSec(1000);                                                     // settling time

    INTEnableSystemMultiVectoredInt();                              // allow vectored interrupts
    initTimer();                                                    // initialise the millisecond timer
    initVideo();                                                    // initialise the video and associated interrupt
    initVT100();                                                    // initialise the vt100/vt52 decoding engine
    initFont(1);                                                    // set the default font
    initSerial();                                                   // initialise the UART used for the serial I/O
    initKeyboard();                                                 // initialise the keyboard and associated interrupt

    INTEnableInterrupts();

    uSec(100000);                                                   // allow everything to settle
	if(Option[O_STARTUPMSG]) VideoPrintString(MES_SIGNON); 			// print signon message

    while(1) {
        checkKeyboard();
        ShowCursor(true);

        ch = getSerial();
        if(ch != -1) VT100Putc(ch);
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
